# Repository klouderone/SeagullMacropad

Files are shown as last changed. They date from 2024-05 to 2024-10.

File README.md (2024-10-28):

# The Seagull Macropad by Kea Workshop

Built Choc Seagull Macropad 1000px

The Seagull Macropad is based off the Rhino Pad, that supports both MX and Choc switches. The Macropad features an aesthetic but functional diode layout, an encoder, and pads for a battery and battery switch for wireless support. The PCB is held in the case in a sandwich mount style, and uses magnets to keep the case together. The board is MX spaced, not Choc spaced. 

Features:

- 16 Switches, 1 Encoder
- Pro Micro / Elite C footprint
- Supports MX and Choc Hotswap Switches
- Supports wireless Microcontrollers; built in battery pads and battery switch pads
- Magnetic Sandwich Case (16x 3mm Diameter x 2mm Height)

## Build Guide

This build is a medium-hard build. It is recommended that you use solder paste for the diodes, as it takes patience and a steady hand to solder them using an Iron.

**PLEASE MAKE SURE TO READ THE WHOLE GUIDE BEFORE COMMENCING BUILD.**

**Parts Needed:**
- 1x Seagull Numpad PCB
- 16x Kailh Choc Hot Swap Sockets
- 16x Kailh MX Hot Swap Sockets
- 2x B3U-1000P Tactile Button (extra for mistake)
- 24x Mill-Max Pins
- 2x 12 Pin Mill-Max Sockets
- 20x 1N4148 SOD-123 Diodes (extra for mistakes)
- 1x EC11 Encoder
- 1x 3 Pin Toggle Switch (MSK-12C02 & PCM12SMTR)
- 16x Choc or MX switches
- 16x Choc or MX keycaps
- 1x Microcontroller (Elite C/Pro Micro/Nice!Nano V2)
- 1x OLED Display with matching header (optional)

### STEP ZERO: Flash Microcontroller with Known Firmware

First thing to do is to flash the microcontroller with the given firmware. This is to ensure that the Microcontroller works properly, and if it doesn't, is returnable/refundable to the vendor you bought it from. If you are using QMK, download the QMK toolbox and the VIAL firmware for your microcontroller, .uf2 for Elite-C RP2040 controllers, or .hex for Pro-Micro ATMega32U4 controllers. A google will be able to show you how to flash for your microcontroller. 

### STEP ONE: Soldering the Reset Button

Soldering the reset button is the most difficult due to its small contacts, though it is not required for the board to work. If you do not want to solder the reset button, you just need to bridge the pads on the back of the board with tweezers to put it into bootloader mode. Carefully and steadily use tweezers to correctly align the button, heat up the tinned pad and place the button onto the pad, remove the heat and let the solder solidify. Then solder the other pad to secure, and possibly add a touch more solder on the first pad.

### STEP TWO: Soldering the Battery Switch (wireless version only)

Soldering the battery switch is a little more complex than the reset button. I reccommend solder paste for this. If you do not use solder paste, tin one pad first. Place the switch onto the pad and hold it steady using tweezers, heat it up, and push it into the solder and let it solidify. Carefully solder all other pads to the PCB.

### STEP THREE: Soldering the diodes 

There are two ways to do this, both require tweezers;

Option One: using solder paste and a heat gun (hairdryer may work)

Apply solder paste into all the diode pads. Use your tweezers to carefully place the diodes in the correct orientation on top of the pads. Gently apply heat using a hot plate or a heat gun, and watch the diodes pull themselves into place.

Option Two: using, a clean soldering iron, a steady hand, and patience.

Tin the top pad of all the diode pads. Carefully and steadily use tweezers hold and correctly align the diode, heat up the tinned pad, and place the diode onto the pad. Then, solder the other pad to secure. Repeat process going from left to right, top row to bottom row. See diagram below for recommended setup for this.

Soldering Diagram

### STEP FOUR: Solder Hotswap Sockets

Tin one of the Hotswap pads. Place your hotswap socket into the holes, and heat up the tinned pad side while adding solder. Make sure to touch the pad or the contact of the hotswap socket that is on the pad. After a good connection, remove heat and solder other side. Repeat for all. I recommend pushing the hotswap socket in while soldering to get a good solder joint.

### STEP FIVE: Soldering Mill-Max sockets to PCB

To do this correctly, you want to put the sockets into the PCB holes, and also put the Microcontroller on top to align them perpendicular to the PCB. Use putty or you finger to keep the sockets aligned and solder them into place.

### STEP SIX: Soldering Microcontroller to the Mill-Max Pins

Place the microcontroller onto the sockets, aligning the pins with the through-holes, and carefully solder. Make sure you do not leave the iron on the pins/through-holes for too long, as you risk burning the traces of the microcontoller. Be sure to not use too much solder, as if you use too much it can flow down through the hole and join the socket and microcontroller. It is better to do too little and go back after later. Carefully remove the microcontroller to confirm that the joints are good. When removing, pull uniformly from both the USB side and the bottom side. Failure to do this can result in bending the Mill-Max pins. I have found using a switch puller to be handy doing this.

### STEP SEVEN: Soldering Display Pins

On the PCB, the display pins are noted of their output. If you are using an OLED display, disregard the CS pin (this is used for e-paper displays like the nice!view). If you are using Mill-Max sockets, you want a PH5 (plastic height 5) box header.  You can then solder the box header. 

### STEP EIGHT: Soldering the Encoder

Make sure the Encoder is flat up against the PCB when soldering. First solder the signal pins (as they require less heat than the locking pins) to hold the encoder in place, and then solder the locking pins. 

### STEP NINE: Soldering the Battery (wireless version only)

With the microcontroller out of the Mill-Max sockets, carefully solder the positive lead of the battery to the positive pad, and the negative lead to the negative pad. DO NOT LET THESE TWO LEADS TOUCH! 

### STEP TEN: 

Reinsert your microcontroller, install your switches and keycaps, and enjoy your new Macropad!

## Firmware

Known Issues: 
- NA

## Sponsorship - PCBWay
I ordered my PCB's off PCBWay.
I am very satisfied with the quality of the boards I recieved, and they came with no visible imperfections and all worked as intended!
The service they provide is great, and they give you lots of different settings to chose from depending on what you need your PCB to be
Thanks again to PCBway for sponsoring this project! I am very pleased to have this project sponsored by them!

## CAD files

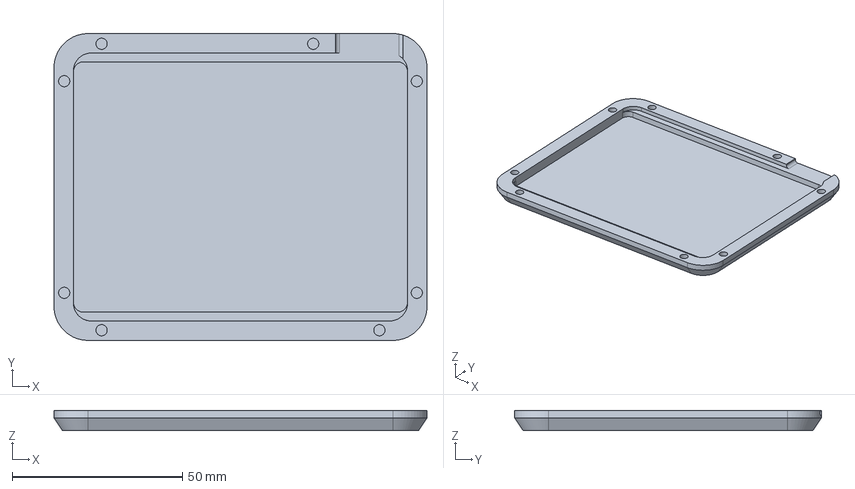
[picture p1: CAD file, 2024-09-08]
3D Printed Case/Bottom Case.stp
109.6 x 90.2 x 6.00 mm

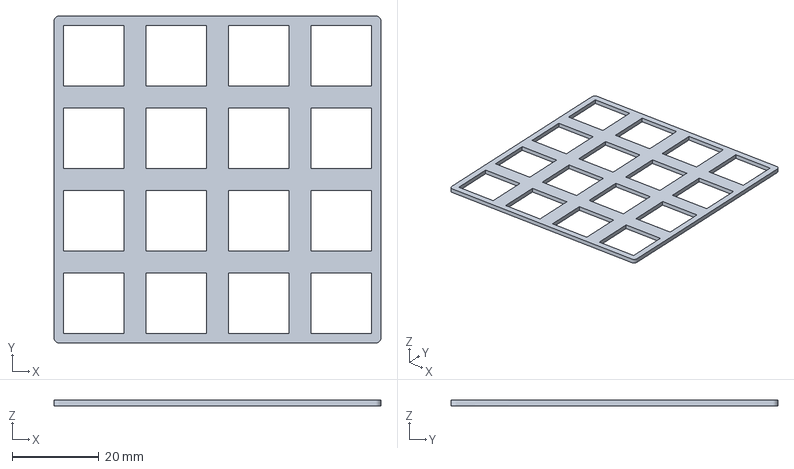
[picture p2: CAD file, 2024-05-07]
3D Printed Case/Switch Plate.stp
75.4 x 75.4 x 1.35 mm

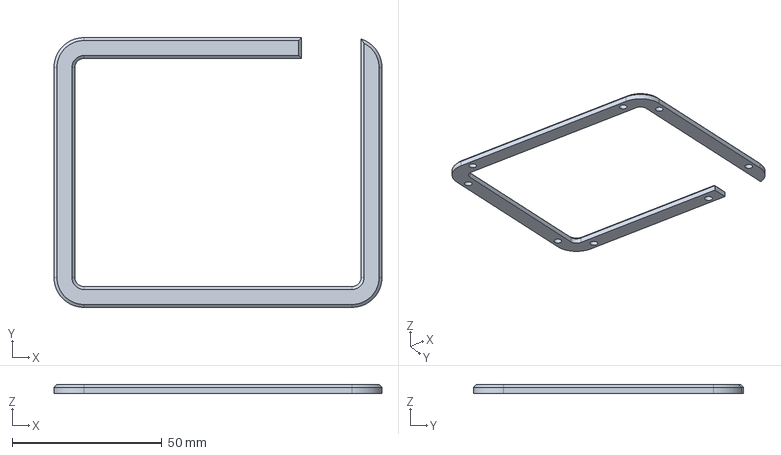
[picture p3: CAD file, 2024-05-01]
3D Printed Case/Top Case.stp
109.7 x 90.2 x 3.15 mm

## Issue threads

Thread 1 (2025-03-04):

Keycap and Dial STLs?

malpern, 2025-03-04:
I love the Seagull design and am going to try to make a set of them for a workshop at a local maker space.  Have you published the STL files for the keycaps and dial? Thank you for open sourcing this project.

malpern, 2025-03-04:
Ah found the keycaps in the other repository but still looking for the dial. https://github.com/klouderone/KEA-choc-keycaps

klouderone, 2025-03-04:
Hey mate, I appreciate the love! That sounds awesome, I would love to get some photos of them all once you've made them! It'll be so cool to see them all lined up! You can find the dial here! https://www.printables.com/model/1000044-ec11-encoder-knob

malpern, 2025-03-12:
Hi, can I get your advice on ordering Seagull PCBs? I'm still a beginner. I initially tried ordering from JLCPCB b/c I'd heard they were less expensive.
# JLCPCB

 I was able to upload your Seagull Production Files.zip file, but I also want them to do the PCB Assembly of the top side given the small surface mounted components and the fact that I want a batch of them. To accomplish that I needed to upload a BOM file and CPL file.

 I opened the Seagull.kicad_pcb in Kicad. I went to the Schematic Editor and Tools → Generate Build of materials and exported the doc.

```
"Reference","Qty","Value","DNP","Exclude from BOM","Exclude from Board","Footprint","Datasheet"
"CH1,CH2,CH3,CH4,CH5,CH6,CH7,CH8,CH9,CH10,CH11,CH12,CH13,CH14,CH15,CH16","16","choc_SW_HS","","","","ClaudeFoot:SW_MXchoc_HS_1u","~"
"D1,D2,D3,D4,D5,D6,D7,D8,D9,D10,D11,D12,D13,D14,D15,D16,D17","17","1N4148W","","","","Diode_SMD:D_SOD-123","https://www.vishay.com/docs/85748/1n4148w.pdf"
"Display1","1","nice!view","","","","PCM_nice_view:nice_view","https://nicekeyboards.com/docs/nice-view/pinout-schematic"
"S1","1","B3U-1000P","","","","ClaudeFoot:B3U-1000P",""
"SW1","1","PCM12SMTR","","","","Button_Switch_SMD:SW_SPDT_PCM12",""
"U1","1","nice_nano","","Excluded from BOM","","ClaudeFoot:Universal_Pro_Micro_Footprint","https://nicekeyboards.com/docs/nice-nano/pinout-schematic"
"U3","1","~","","","","PCM_marbastlib-various:ROT_Alps_EC11E-Switch",""
```

To create the CPL file I went to the PCB Editor, File → Fabrication Outputs → Footprint Position (.pos) File and generated a csv file.

[### Footprint positions - created on 2025-03-12T15:52:23-0700 ###
## Unit = mm, Angle = deg.
## Side : All
# Ref     Val        Package                PosX       PosY       Rot  Side
D17       1N4148W    D_SOD-123         -163.5500  -116.8500  135.0000  bottom
S1        B3U-1000P  B3U-1000P         -164.3380   -67.0560  -90.0000  bottom
D1        1N4148W    D_SOD-123          158.7975  -116.9675  -135.0000  top
D2        1N4148W    D_SOD-123          163.0837  -116.9675  -135.0000  top
D3        1N4148W    D_SOD-123          167.8462  -116.9675  -135.0000  top
D4        1N4148W    D_SOD-123          172.1325  -116.9675  -135.0000  top
D5        1N4148W    D_SOD-123          158.7975  -121.2537  -135.0000  top
D6        1N4148W    D_SOD-123          163.0837  -121.2537  -135.0000  top
D7        1N4148W    D_SOD-123          167.8462  -121.2537  -135.0000  top
D8        1N4148W    D_SOD-123          172.1325  -121.2537  -135.0000  top
D9        1N4148W    D_SOD-123          158.7975  -126.0162  -135.0000  top
D10       1N4148W    D_SOD-123          163.0837  -126.0162  -135.0000  top
D11       1N4148W    D_SOD-123          167.8462  -126.0162  -135.0000  top
D12       1N4148W    D_SOD-123          172.1325  -126.0162  -135.0000  top
D13       1N4148W    D_SOD-123          158.7975  -130.3025  -135.0000  top
D14       1N4148W    D_SOD-123          163.0837  -130.3025  -135.0000  top
D15       1N4148W    D_SOD-123          167.8462  -130.3025  -135.0000  top
D16       1N4148W    D_SOD-123          172.1325  -130.3025  -135.0000  top
## End](url)

Turns out the format didn't match what JLCPCB was expecting:
JLCPCB sample CPL file: https://static.jlcpcb.com//video/JLCSMT_Sample_CPL1.xlsx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.

JLCPCB BOM sample: https://static.jlcpcb.com//video/Sample-BOM_JLCSMT.xlsx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.

 so I edit the csv files by hand. I also removed the MCU since I don't want Nice Nanos (will be doing pro-micros for this build).

BOM File in JLCPCB format
```
Comment,Designator,Footprint,JLCPCB Part #（optional）
1N4148W,"D2,D1,D5,D13,D16,D10,D4,D12,D8,D6,D11,D14,D3,D9,D15,D7,D17",D_SOD-123,
PCM12SMTR,SW1,SW_SPDT_PCM12,
~,U3,ROT_Alps_EC11E-Switch,
B3U-1000P,S1,B3U-1000P,
choc_SW_HS,"CH1,CH3,CH12,CH9,CH8,CH11,CH10,CH5,CH6,CH4,CH7,CH16,CH13,CH15,CH2,CH14",SW_MXchoc_HS_1u,

```
CPL File in JLCPCB format
```
Designator,Mid X,Mid Y,Layer,Rotation
D17,-163.5500,-116.8500,135.000000,bottom
S1,-164.3380,-67.0560,-90.000000,bottom
D1,158.7975,-116.9675,-135.000000,top
D2,163.08375,-116.9675,-135.000000,top
D3,167.84625,-116.9675,-135.000000,top
D4,172.1325,-116.9675,-135.000000,top
D5,158.7975,-121.2537,-135.000000,top
D6,163.08375,-121.2537,-135.000000,top
D7,167.84625,-121.2537,-135.000000,top
D8,172.1325,-121.2537,-135.000000,top
D9,158.7975,-126.0162,-135.000000,top
D10,163.08375,-126.0162,-135.000000,top
D11,167.84625,-126.0162,-135.000000,top
D12,172.1325,-126.0162,-135.000000,top
D13,158.7975,-130.3025,-135.000000,top
D14,163.08375,-130.3025,-135.000000,top
D15,167.84625,-130.3025,-135.000000,top
D16,172.1325,-130.3025,-135.000000,top
```

JLCPCB kept throwing errors and wouldn't process the files

# PCB Way
Then I tried using PCBWay because I saw they sponsored the project. I submitted the Seagull Production Files.zip files. They wrote back and said, "There are some vias-in-pad in your file. Please check if we need to fill these vias with resin. If so, should we only fill vias-in-pad with resin or fill all the vias with resin? Note: For an assembly order, if we don't fill vias-in-pad with resin, it will decrease the area of soldering, which will have a risk of poor soldering, so please consider it."

With ChatGPT's help, I responded, "Please fill only the vias-in-pad with resin to ensure good solderability for the switches. Other vias can remain unfilled."

Now PCBWay is asking for the BOM and Centroid, and other files such as assembly instructions. I'm not sure how to generate these files in PCBWay's expected format.My goal is to have PCBWay (or JLCPCB) manufacture the PCBs, acquire the supplies needed for the top half BOM and assemble the boards, but I can't seem to generate the needed files.

# Advice?
Could you offer any advice on generating BOM and Centroid files in a way that's compatible with PCBWay (or JLCPCB) and confirm that I'm including the right components to assemble the top half of the board? (Having them assemble both sides seems prohiptively expensive so I'll solder the 2 bottom components myself). Thanks again for open sourcing the project.

klouderone, 2025-03-15:
Hey mate,

Unfortunately I am unable to offer any help here, I've never used PCBA and have always just assembled myself as it is cheaper.

I have no idea what it would take to get this ready for PCBA and I don't quite have the time to look into it myself.

Sorry I cannot be of more help, there may be a discord that could be of more help than me.

Claude

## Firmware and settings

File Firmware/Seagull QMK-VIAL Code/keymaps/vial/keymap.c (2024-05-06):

/* Copyright 2021 gkeyboard
 *
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
 * You should have received a copy of the GNU General Public License
 * along with this program.  If not, see <http://www.gnu.org/licenses/>.
 */
#include QMK_KEYBOARD_H

#define _BL 0 

#define _______ KC_TRNS


const uint16_t PROGMEM keymaps[][MATRIX_ROWS][MATRIX_COLS] = {

    // Default layer
    [_BL] = LAYOUT(

    KC_KP_7,              KC_KP_8,              KC_KP_9,        KC_KP_SLASH,       
	KC_KP_4,              KC_KP_5,              KC_KP_6,        KC_KP_ASTERISK,
    KC_KP_1,              KC_KP_2,              KC_KP_3,        KC_KP_MINUS,
    KC_KP_0,              KC_KP_DOT,            KC_KP_EQUAL,    KC_KP_PLUS

    )
};

#if defined(ENCODER_MAP_ENABLE)
const uint16_t PROGMEM encoder_map[][NUM_ENCODERS][2] = {
    [0] =   { ENCODER_CCW_CW(KC_VOLD, KC_VOLU)}
    //                  Encoder 1                                  
};
#endif


#ifdef OLED_ENABLE

bool oled_task_user() {
  static const char image [] PROGMEM = {

// 'rhino pad kea workshop', 128x32px
0x00, 0x00, 0x00, 0x00, 0xf0, 0xf8, 0x4c, 0xc6, 0x82, 0x1a, 0x12, 0x1a, 0x02, 0x06, 0x0c, 0x38, 
0x60, 0xc0, 0x80, 0x00, 0x00, 0x00, 0x00, 0x00, 0x00, 0x00, 0x00, 0x00, 0x00, 0x00, 0x00, 0x00, 
0x00, 0x00, 0x00, 0x00, 0x00, 0x00, 0x00, 0x00, 0x00, 0x00, 0x00, 0x00, 0x00, 0x00, 0x00, 0x00, 
0x00, 0x00, 0x00, 0x00, 0x00, 0x00, 0x00, 0x00, 0x00, 0x00, 0x00, 0x00, 0x00, 0x00, 0x00, 0x00, 
0x00, 0x00, 0x00, 0x00, 0x00, 0xfc, 0xfc, 0xc0, 0xe0, 0xb0, 0x1c, 0x0c, 0x00, 0x00, 0x00, 0xfc, 
0xfc, 0x44, 0x44, 0x44, 0x4c, 0x4c, 0x00, 0x00, 0xc0, 0xf0, 0x3c, 0x0c, 0x0c, 0x3c, 0xf0, 0xc0, 
0x00, 0x00, 0x00, 0x00, 0x00, 0x00, 0x00, 0x00, 0x00, 0x00, 0x00, 0x00, 0x00, 0x00, 0x00, 0x00, 
0x00, 0x00, 0x00, 0x00, 0x00, 0x00, 0x00, 0x00, 0x00, 0x00, 0x00, 0x00, 0x00, 0x00, 0x00, 0x00, 
0x00, 0x00, 0x00, 0x00, 0x01, 0x01, 0x00, 0x00, 0x03, 0xfe, 0xc0, 0x40, 0x40, 0x40, 0x20, 0x20, 
0x00, 0xf8, 0x01, 0x03, 0x02, 0x06, 0x0c, 0x18, 0x30, 0x60, 0xc0, 0x80, 0x00, 0x00, 0x00, 0x00, 
0x00, 0x00, 0x00, 0x00, 0x00, 0x00, 0x00, 0x00, 0x00, 0x00, 0x00, 0x40, 0x40, 0x40, 0x40, 0x40, 
0x40, 0x40, 0x40, 0x40, 0x40, 0x40, 0x40, 0x40, 0x40, 0x40, 0x40, 0x40, 0x40, 0x40, 0x40, 0x40, 
0x40, 0x40, 0x40, 0x40, 0x40, 0x4f, 0x4f, 0x40, 0x41, 0x43, 0x47, 0x4e, 0x4c, 0x40, 0x40, 0x4f, 
0x4f, 0x48, 0x48, 0x48, 0x4c, 0x4c, 0x40, 0x40, 0x4f, 0x4f, 0x41, 0x41, 0x41, 0x41, 0x4f, 0x4f, 
0x40, 0x40, 0x40, 0x40, 0x40, 0x40, 0x40, 0x40, 0x40, 0x40, 0x40, 0x40, 0x40, 0x40, 0x40, 0x40, 
0x40, 0x40, 0x40, 0x40, 0x40, 0x40, 0x40, 0x40, 0x40, 0x40, 0x40, 0x40, 0x40, 0x00, 0x00, 0x00, 
0x00, 0x00, 0x00, 0x00, 0x00, 0x00, 0x00, 0x00, 0x00, 0x00, 0x03, 0x06, 0x1c, 0x38, 0x68, 0xc8, 
0x8c, 0x06, 0x03, 0x06, 0x8c, 0xd8, 0x90, 0x30, 0x20, 0x60, 0xc0, 0x81, 0x83, 0x06, 0x0c, 0x18, 
0x30, 0x60, 0xc0, 0x00, 0x00, 0x00, 0x00, 0x00, 0x00, 0x00, 0x00, 0x32, 0xf2, 0x82, 0x02, 0x82, 
0xe2, 0xe2, 0xe2, 0x82, 0x02, 0x82, 0xf2, 0x72, 0x02, 0xc2, 0xe2, 0x32, 0x12, 0x12, 0x12, 0x12, 
0xe2, 0xc2, 0x02, 0x02, 0xe2, 0xf2, 0x12, 0x12, 0x12, 0x12, 0xf2, 0xe2, 0x02, 0x02, 0xf2, 0xf2, 
0x02, 0x82, 0xc2, 0x72, 0x32, 0x02, 0x02, 0x02, 0xe2, 0xf2, 0x12, 0x12, 0x12, 0x12, 0x32, 0x62, 
0x02, 0xf2, 0xf2, 0x02, 0x02, 0x02, 0x02, 0xf2, 0xf2, 0x02, 0x02, 0xc2, 0xe2, 0x32, 0x12, 0x12, 
0x12, 0x32, 0xe2, 0xc2, 0x02, 0x02, 0xe2, 0x32, 0x12, 0x12, 0x12, 0x32, 0xe2, 0x00, 0x00, 0x00, 
0x00, 0x00, 0x00, 0x00, 0x00, 0x00, 0x00, 0x00, 0x00, 0x00, 0x00, 0x00, 0x00, 0x00, 0x60, 0x60, 
0x61, 0x27, 0x3c, 0x26, 0x63, 0x60, 0x61, 0x27, 0x3c, 0x26, 0x23, 0x00, 0x01, 0x01, 0x03, 0x02, 
0x06, 0x0c, 0x09, 0x0b, 0x0e, 0x00, 0x00, 0x00, 0x00, 0x00, 0x00, 0x00, 0x07, 0x1f, 0x38, 0x1f, 
0x07, 0x00, 0x07, 0x1f, 0x38, 0x1f, 0x07, 0x00, 0x00, 0x0f, 0x1f, 0x30, 0x20, 0x20, 0x20, 0x30, 
0x1f, 0x0f, 0x00, 0x00, 0x3f, 0x3f, 0x03, 0x03, 0x03, 0x0f, 0x3f, 0x30, 0x00, 0x00, 0x3f, 0x3f, 
0x03, 0x07, 0x0e, 0x1c, 0x38, 0x30, 0x00, 0x00, 0x18, 0x31, 0x21, 0x23, 0x23, 0x22, 0x3e, 0x1c, 
0x00, 0x3f, 0x3f, 0x01, 0x01, 0x01, 0x01, 0x3f, 0x3f, 0x00, 0x00, 0x0f, 0x1f, 0x30, 0x20, 0x20, 
0x20, 0x30, 0x1f, 0x0f, 0x00, 0x00, 0x3f, 0x3f, 0x06, 0x06, 0x02, 0x03, 0x01, 0x00, 0x00, 0x00
};

//draw image to OLED
oled_write_raw_P(image, sizeof(image));

    return false;
}



bool dip_switch_update_user(uint8_t index, bool active) {
    switch (index) {
        case 0: {
            if (active) {
                tap_code(KC_MUTE);
            } else {
                
            }
        }
    }
    return true;
}

#endif

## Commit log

2024-04-30 Kicad Files and Production Gerbers
    [Tired Seagull.kicad_sch]
2024-05-01 V3 Commit
    Added diode for encoder as VIAL does not support direct key, must be in a matrix.
    [Tired Seagull.kicad_sch]
2024-05-01 Firmware Commit
    VIAL Firmware for ATMega32U4 Pro Micro based boards and RP2040 Elite Pi based boards.
2024-05-01 Add 3D Printed Case
    [Bottom Case.stp, Top Case.stp]
2024-09-08 fixed broken bottom case
    [Bottom Case.stp]

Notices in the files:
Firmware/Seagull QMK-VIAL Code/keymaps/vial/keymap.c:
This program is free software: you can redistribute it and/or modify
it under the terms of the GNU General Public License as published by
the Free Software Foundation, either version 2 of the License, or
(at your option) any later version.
